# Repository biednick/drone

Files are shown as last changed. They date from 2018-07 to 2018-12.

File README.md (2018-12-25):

# Drones

The drone features 3 oscillators and a tone control, which can be passivly mixed to combine as many oscillators as you want.

## Files
droneSlave_xx .brd and .sch
These are the board and schematic files needed to manufacture PCBs. Gerbers need to be generated in Eagle for manufacturing.

### slaveParts_xx.md
These are the parts lists for each module. A mouser BOM is available in this file as well.

### slavePanel.ai
These are the panels in Adobe Illustrator format. I make my panels on a laser cutter with 1/8 inch acrylic.

## Updates

### 01.1 22AUG18 
Removed the master files because it doesn't work at all.

### 01 25JUN18
First push to GitHub. The slave module has been tested, but the master is untested.

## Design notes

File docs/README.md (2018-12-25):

# Drone

#### [Overview](#overview) | [Design](#design)

### Overview

Featuring 3 reverse avalanche saw oscillators and tone control, this module may be passivle mixed to build an array of as many oscillators as you would like.

### Design

One of my few purely analog modules, this module features three of the simplest oscillators possible. The transisistors and capacitors can be socketed, allowing you to experiment with different transistors and dial in the perfect frequency range.

### Buy

I'll be updating this part soon with a link to buy PCBs on Reverb. For the time being you can email me to purchase development PCBs at a discount. These will be fully functional but have minor issues. In the case of the Drone PCB, the back silkscreen is missing.

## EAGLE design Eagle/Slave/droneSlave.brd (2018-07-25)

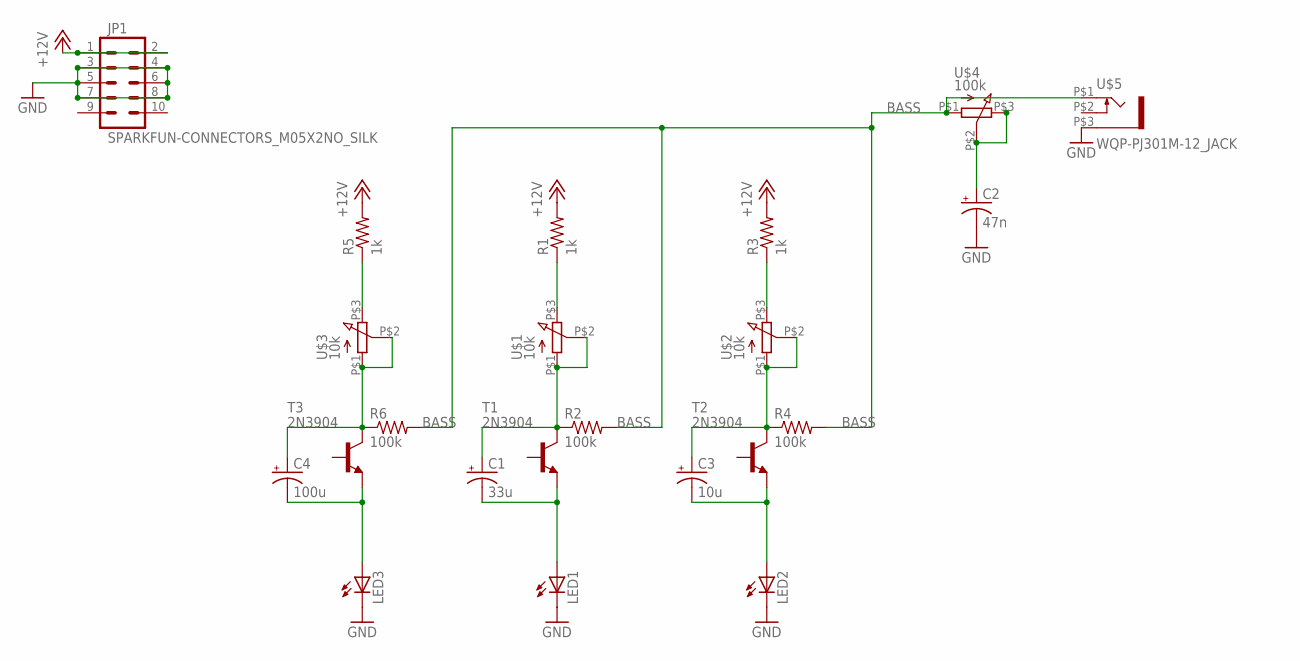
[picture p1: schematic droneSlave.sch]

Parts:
C1: 33u; E2,5-7
C2: 47n; E2,5-7
C3: 10u; E2,5-7
C4: 100u; E2,5-7
JP1: SPARKFUN-CONNECTORS_M05X2NO_SILK; SPARKFUN-CONNECTORS_2X5_NOSILK
LED1, LED2, LED3: LED5MM
R1, R3, R5: 1k; 0204/7
R2, R4, R6: 100k; 0204/7
T1, T2, T3: 2N3904; TO92
U$1, U$2, U$3: 10k; INSTRUO_Q-POT
U$4: 100k; INSTRUO_Q-POT
U$5: WQP-PJ301M-12_JACK

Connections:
+12V: JP1.1, JP1.2, R1.2, R3.2, R5.2
BASS: R2.2, R4.2, R6.2, U$4.P$1 (1), U$5.P$1 (2)
GND: C2.-, JP1.3, JP1.4, JP1.5, JP1.6, JP1.7, JP1.8, LED1.K (C), LED2.K (C), LED3.K (C), U$5.P$3 (1)
unnamed: R1.1, U$1.P$3 (3)
unnamed: C1.+, R2.1, T1.1 (C), U$1.P$1 (1), U$1.P$2 (2)
unnamed: C1.-, LED1.A, T1.3 (E)
unnamed: R3.1, U$2.P$3 (3)
unnamed: C3.+, R4.1, T2.1 (C), U$2.P$1 (1), U$2.P$2 (2)
unnamed: C3.-, LED2.A, T2.3 (E)
unnamed: R5.1, U$3.P$3 (3)
unnamed: C4.+, R6.1, T3.1 (C), U$3.P$1 (1), U$3.P$2 (2)
unnamed: C4.-, LED3.A, T3.3 (E)
unnamed: C2.+, U$4.P$2 (2), U$4.P$3 (3)

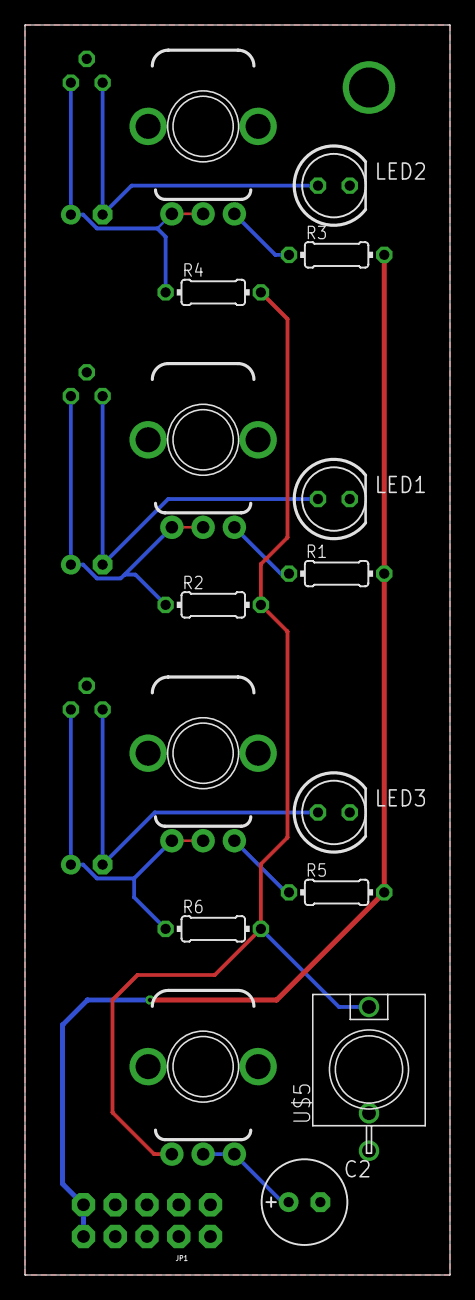
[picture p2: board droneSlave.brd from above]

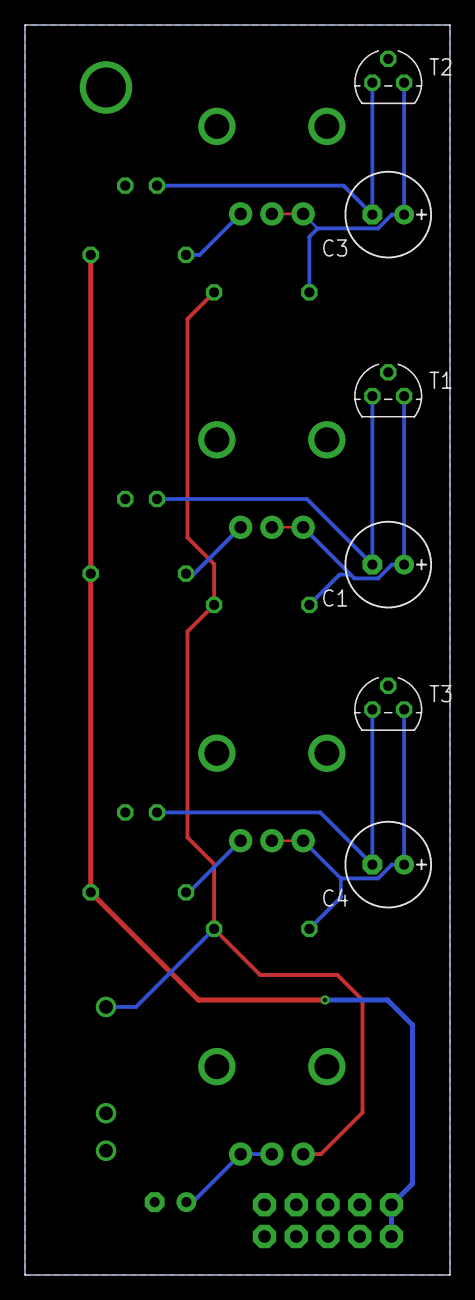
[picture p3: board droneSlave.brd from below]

Board: 2 copper layers, 34.0 x 100.0 mm, 22 parts (6 on the bottom side), 13 nets.
